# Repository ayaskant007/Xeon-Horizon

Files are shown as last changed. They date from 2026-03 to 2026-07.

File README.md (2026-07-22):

# Xeon Horizon Macropad

The **Xeon Horizon** is a high-performance, 35mm tall programmer's macropad powered by the Seeed Studio XIAO RP2040. It is designed specifically for ultra-fast workflows in code editors, featuring dedicated refactoring/debugging shortcuts, a rotary encoder for rapid code navigation, and a status OLED. 

A unique feature of the Horizon is its upward-facing SK6812 MINI E RGB lighting, which shines directly through hollowed-out text on the top plate to act as an aggressive, high-contrast indicator light.

---

## Project Showcase

[Demo Video](https://youtu.be/cCljSfHtNLw?si=nqkD094vY3MVkHw3)



Built Project

### The Hackpad
Overall Hackpad

### Case Assembly
Case Assembly

### Printed Circuit Board (PCB)
PCB Layout

### Schematic
Schematic

---

## Features & Keymap
* **Controller:** Seeed Studio XIAO RP2040
* **Firmware:** QMK (Direct Pin Matrix, Custom Encoder Map)
* **OLED Display:** SSD1306 (I2C) displaying "XEON HORIZON" and "PROG_MODE" status.
* **Lighting:** 4x SK6812 MINI E LEDs running at maximum brightness for Top-Down hollow text illumination.

### Default Shortcuts:
* **Key 1:** Copy (`Ctrl + C`)
* **Key 2:** Paste (`Ctrl + V`)
* **Key 3:** Undo (`Ctrl + Z`)
* **Key 4:** Run/Debug (`F5`)
* **Key 5:** Execute/Submit (`Enter`)
* **Encoder CW:** Scroll Down (`Mouse Wheel Down`)
* **Encoder CCW:** Scroll Up (`Mouse Wheel Up`)

---

## Bill of Materials (BOM)

| Item | Quantity | Description / Notes |
| :--- | :---: | :--- |
| **Microcontroller** | 1 | Seeed Studio XIAO RP2040 |
| **Switches** | 4 | MX-compatible mechanical switches |
| **Keycaps** | 4 | 1U Keycaps |
| **Rotary Encoder** | 1 | EC11 Rotary Encoder (with push-button) |
| **Encoder Knob** | 1 | Standard encoder knob |
| **Display** | 1 | 0.91" I2C OLED Display (SSD1306) |
| **LEDs** | 4 | SK6812 MINI E RGB LEDs |
| **PCB** | 1 | Custom Xeon Horizon PCB |
| **Case (Top Plate)**| 1 | 3D Printed Top Plate with hollow text (`Top_Plate.STEP`) |
| **Case (Base)** | 1 | 3D Printed 35mm deep base (`Case.STEP`) |
| **Wiring** | ~ | Hookup wire (for hand-wiring components to the XIAO) |

---

## Build & Flash Instructions
1. Assemble the hardware according to the schematic and the 3D CAD designs.
2. Set up your QMK MSYS environment.
3. Copy the `xeon` firmware folder into `qmk_firmware/keyboards/`.
4. Compile the firmware: `qmk compile -kb xeon -km default`
5. Double-tap the reset button on the XIAO RP2040.
6. Drag and drop the generated `.uf2` file into the `RPI-RP2` drive.

---

## Bill of Materials (BOM)

| Name | Purpose | Qty | Total (INR) |
| :--- | :--- | :---: | :---: |
| **3D PRINTED CASE FROM PRINTING LEGION** | For volume control | 1 | 300INR |
| **HACKPAD KIT FROM HACK CLUB** | for getting the components for the pcb | 1 | - |
| **PCB FROM LIONCIRCUITS** | for getting the components for the pcb | 1 | 1200INR |

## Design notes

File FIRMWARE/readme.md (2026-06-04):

# Xeon Horizon

A high-performance programmer macropad built on the **Seeed Studio XIAO RP2040**.

* Keyboard Maintainer: [Ayaskant Sahoo](https://github.com/ayaskant007)
* Hardware Supported: Seeed Studio XIAO RP2040, SSD1306 128×32 OLED, 4× SK6812MINI-E RGB LEDs, Rotary Encoder, 4X Cherry MX Switches
* Hardware Availability: Custom PCB

## Features

| Control | Layer 0 (PROG_MODE) | Layer 1 (NAV_MODE) | Layer 2 (MUSIC_MODE) | Layer 3 (SYS_MODE) |
|---|---|---|---|---|
| Key 1 | Copy (Ctrl+C) | Cut (Ctrl+X) | Prev Track | Bootloader (`QK_BOOT`) |
| Key 2 | Paste (Ctrl+V) | Redo (Ctrl+Y) | Play/Pause | Toggle RGB |
| Key 3 | Undo (Ctrl+Z) | Save (Ctrl+S) | Next Track | RGB Brightness Down |
| Key 4 | Run/Debug (F5) | RGB Mode Toggle | Mute | RGB Brightness Up |
| Encoder Press | Switch to NAV | Switch to MUSIC | Switch to SYS | Switch to PROG |
| Encoder CW | Scroll Down | Next Tab | Volume Up | RGB Mode Next |
| Encoder CCW | Scroll Up | Prev Tab | Volume Down | RGB Mode Prev |

## Building

    qmk compile -kb xeon -km default

## Flashing

    qmk flash -kb xeon -km default

Or manually: double-press the BOOT button on the XIAO RP2040, then drag the `.uf2` file from `.build/` onto the USB drive that appears.

## Bootloader

Enter the bootloader in 3 ways:

* **Bootmagic reset**: Hold down Key 1 (top-left) and plug in the keyboard
* **Physical reset button**: Double-press the BOOT button on the XIAO RP2040
* **Keycode in layout**: Press the Encoder until you reach `SYS_MODE` (Layer 3), then press Key 1 (top-left).

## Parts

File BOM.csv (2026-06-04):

Name | Purpose | Quantity | Total Cost (USD) | Link | Distributor
3d printed case | for holding the pcb | 1 | ? 300.00 |  | Printing Legion
Hackpad Kit | FOR GETTING THE COMPONENTS | 1 | ? 0.00 |  | Hack Club
PCB |  | 1 | ? 1,200.00 |  | Lion Circuits
 |  |  | ? 1,500.00

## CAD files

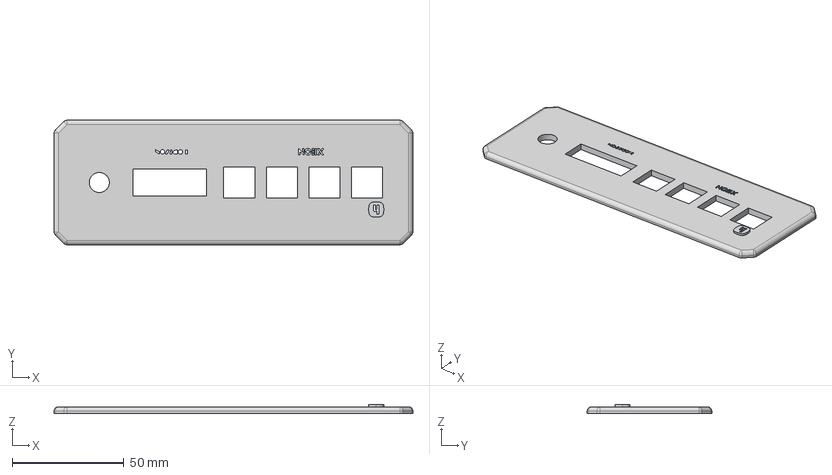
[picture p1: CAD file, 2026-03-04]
production/Top Plate.step
160.8 x 55.8 x 4.00 mm

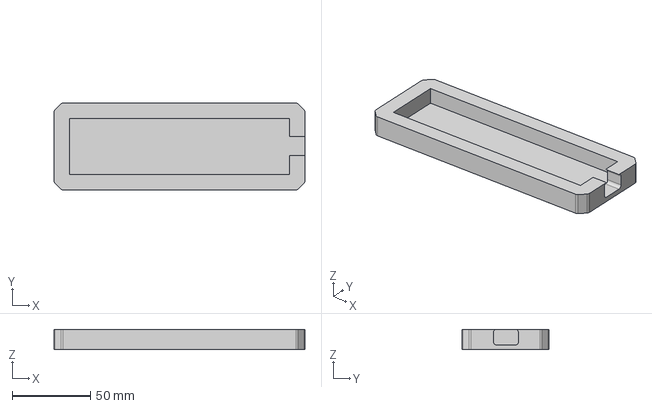
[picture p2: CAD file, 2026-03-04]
production/Case.step
160.8 x 55.8 x 13.0 mm

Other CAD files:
Assembly.f3z

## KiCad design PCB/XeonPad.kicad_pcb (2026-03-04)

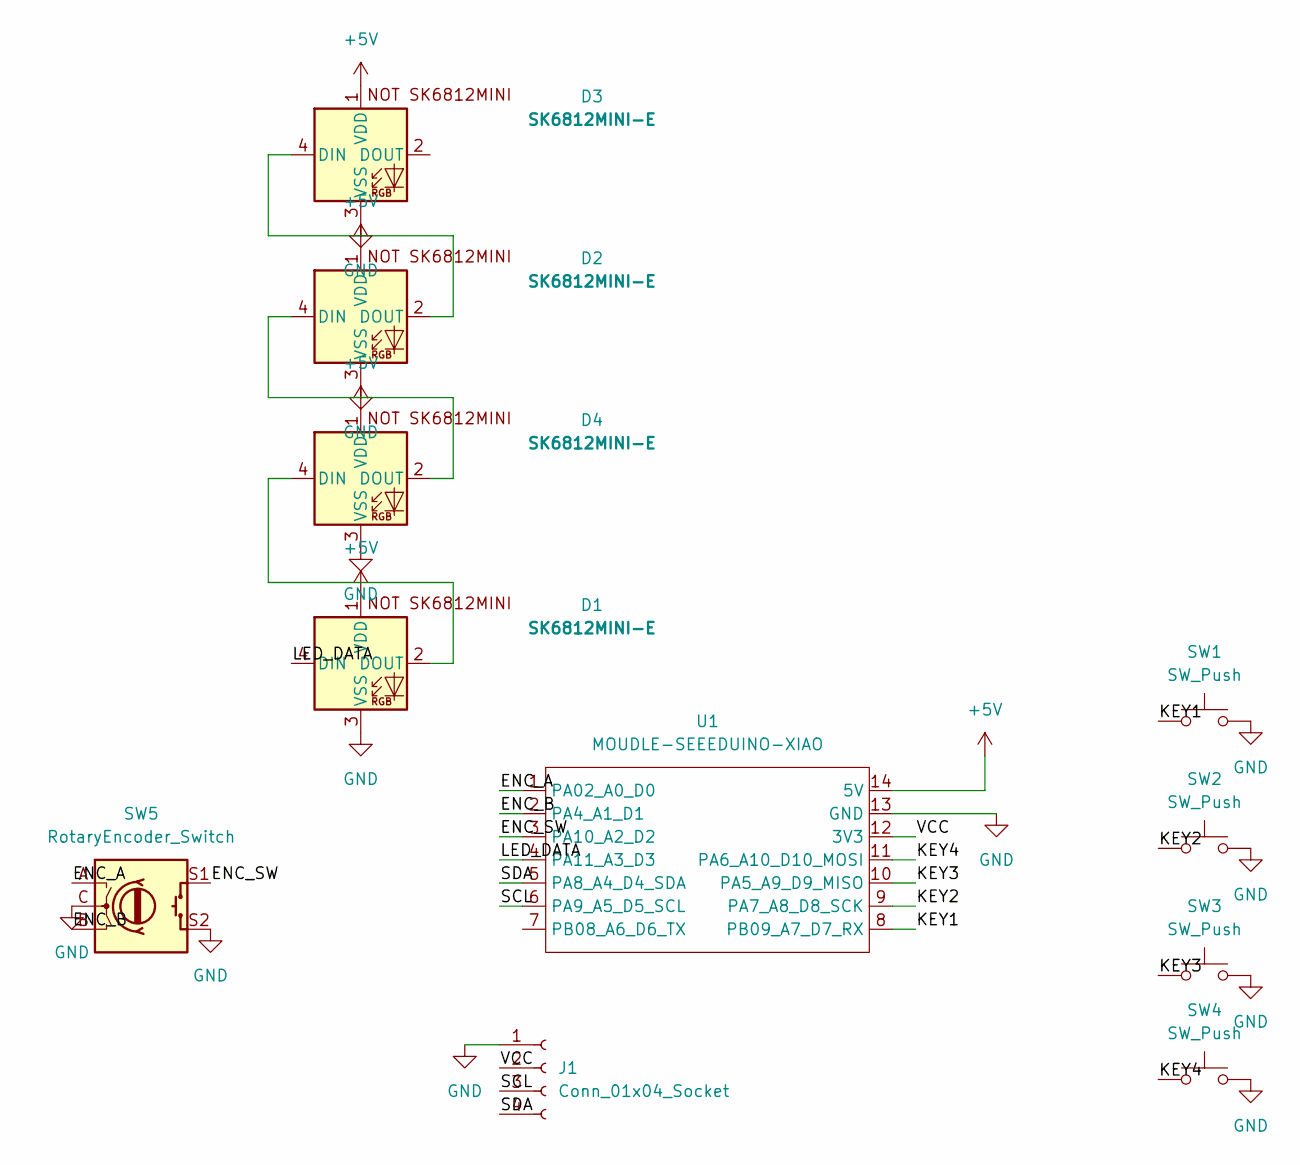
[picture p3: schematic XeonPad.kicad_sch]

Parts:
D1, D2, D3, D4: SK6812MINI-E; SK6812MINI-E_fixed
J1: Conn_01x04_Socket; PinHeader_1x04_P2.54mm_Vertical
SW1, SW2, SW3, SW4: SW_Push; SW_Cherry_MX_1.00u_PCB
SW5: RotaryEncoder_Switch; RotaryEncoder_Alps_EC11E-Switch_Vertical_H20mm
U1: MOUDLE-SEEEDUINO-XIAO; XIAO-Generic-Hybrid-14P-2.54-21X17.8MM

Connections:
+5V: D1.1 (VDD), D2.1 (VDD), D3.1 (VDD), D4.1 (VDD), U1.14 (5V)
/ENC_A: SW5.A, U1.1 (PA02_A0_D0)
/ENC_B: SW5.B, U1.2 (PA4_A1_D1)
/ENC_SW: SW5.S1, U1.3 (PA10_A2_D2)
/KEY1: SW1.1, U1.8 (PB09_A7_D7_RX)
/KEY2: SW2.1, U1.9 (PA7_A8_D8_SCK)
/KEY3: SW3.1, U1.10 (PA5_A9_D9_MISO)
/KEY4: SW4.1, U1.11 (PA6_A10_D10_MOSI)
/LED_DATA: D1.4 (DIN), U1.4 (PA11_A3_D3)
/SCL: J1.3, U1.6 (PA9_A5_D5_SCL)
/SDA: J1.4, U1.5 (PA8_A4_D4_SDA)
/VCC: J1.2, U1.12 (3V3)
GND: D1.3 (VSS), D2.3 (VSS), D3.3 (VSS), D4.3 (VSS), J1.1, SW1.2, SW2.2, SW3.2, SW4.2, SW5.C, SW5.S2, U1.13 (GND)
unnamed: D1.2 (DOUT), D4.4 (DIN)
unnamed: D2.4 (DIN), D4.2 (DOUT)
unnamed: D2.2 (DOUT), D3.4 (DIN)

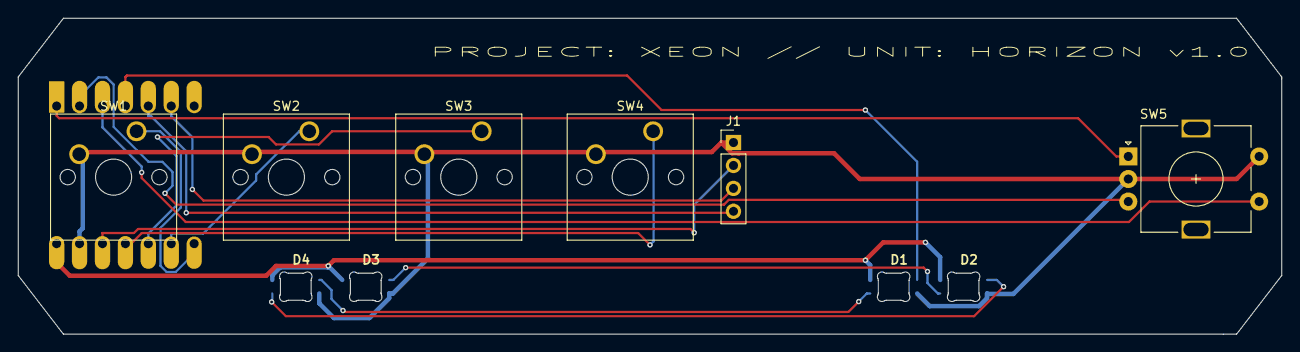
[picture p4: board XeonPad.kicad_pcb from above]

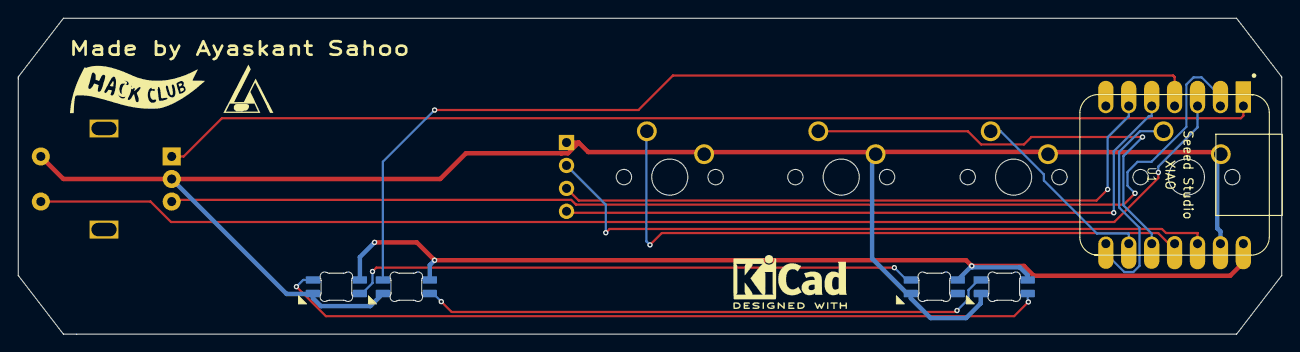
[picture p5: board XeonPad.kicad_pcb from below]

Board: 2 copper layers, 140.0 x 35.0 mm, 12 parts (2 on the bottom side), 16 nets.

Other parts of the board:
logo: LOGO; 007

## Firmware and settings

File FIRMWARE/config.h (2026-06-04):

// Copyright 2024 Ayaskant Sahoo (@ayaskant007)
// SPDX-License-Identifier: GPL-2.0-or-later

#pragma once

/* ── I2C Configuration (OLED on XIAO D4/D5 = GP6/GP7) ── */
#define I2C_DRIVER I2CD2
#define I2C1_SDA_PIN GP6
#define I2C1_SCL_PIN GP7

/* ── OLED Display ── */
#define OLED_DISPLAY_128X32
#define OLED_TIMEOUT 0 /* Always on — shows project identity */

/* ── RGB Light Defaults (Cyber-Blue Breathing) ── */
#define RGBLIGHT_DEFAULT_MODE RGBLIGHT_MODE_BREATHING + 2
#define RGBLIGHT_DEFAULT_HUE 152 /* Cyber-blue hue */
#define RGBLIGHT_SLEEP           /* LEDs off when host sleeps */

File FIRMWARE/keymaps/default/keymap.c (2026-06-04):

// Copyright 2024 Ayaskant Sahoo (@ayaskant007)
// SPDX-License-Identifier: GPL-2.0-or-later

#include QMK_KEYBOARD_H

enum layers { _PROG = 0, _NAV, _MUSIC, _SYS };

/* KEYMAPS */
const uint16_t PROGMEM keymaps[][MATRIX_ROWS][MATRIX_COLS] = {

    /* PROG_MODE (Layer 0) */
    [_PROG] = LAYOUT(LCTL(KC_C),      // Copy
                     LCTL(KC_V),      // Paste
                     LCTL(KC_Z),      // Undo
                     KC_F5,           // Run/Debug
                     TO(_NAV)         // Switch to NAV Layer
                     ),

    /* NAV_MODE (Layer 1) */
    [_NAV] = LAYOUT(LCTL(KC_X),       // Cut
                    LCTL(KC_Y),       // Redo
                    LCTL(KC_S),       // Save
                    UG_NEXT,          // Change RGB Mode (Next)
                    TO(_MUSIC)        // Switch to MUSIC Layer
                    ),

    /* MUSIC_MODE (Layer 2) */
    [_MUSIC] = LAYOUT(KC_MPRV,        // Previous Track
                      KC_MPLY,        // Play/Pause
                      KC_MNXT,        // Next Track
                      KC_MUTE,        // Mute
                      TO(_SYS)        // Switch to SYS Layer
                      ),

    /* SYS_MODE (Layer 3) */
    [_SYS] = LAYOUT(QK_BOOT,          // Bootloader
                    UG_TOGG,          // Toggle RGB
                    UG_VALD,          // RGB Brightness Down
                    UG_VALU,          // RGB Brightness Up
                    TO(_PROG)         // Switch to PROG Layer
                    )};





/* ENCODER MAP */
#if defined(ENCODER_MAP_ENABLE)
const uint16_t PROGMEM encoder_map[][NUM_ENCODERS][NUM_DIRECTIONS] = {
    [_PROG] = {ENCODER_CCW_CW(MS_WHLU, MS_WHLD)}, 
    [_NAV] = {ENCODER_CCW_CW(LCTL(LSFT(KC_TAB)), LCTL(KC_TAB))},
    [_MUSIC] = {ENCODER_CCW_CW(KC_VOLD, KC_VOLU)},
    [_SYS] = {ENCODER_CCW_CW(UG_PREV, UG_NEXT)}
};
#endif

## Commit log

2026-03-04 Added PCB files and PCB production files
    [XeonPad-B_Cu.gbl, XeonPad-B_Mask.gbs, XeonPad-B_Paste.gbp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]
2026-03-04 Added production CAD
    [Case.step, Top Plate.step]
2026-03-04 Updated Readme and put the gerbers in a zip
    [XeonPad-B_Cu.gbl, XeonPad-B_Mask.gbs, XeonPad-B_Paste.gbp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]
2026-03-04 Update Case Assembly image in README.md
2026-03-04 Fix image links in README.md
    Updated image links in the README for Hackpad and PCB Layout.
2026-06-04 Add Bill of Materials section to README
2026-06-04 Add MUSIC/SYS layers, enable RGB, switch I2C
    Introduce new functionality and hardware config updates: add BOM.csv and a board mcuconf.h to enable RP2040 I2C1; switch I2C driver in config.h to I2CD2. Disable OLED support in keyboard.json and rem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
    [BOM.csv]
